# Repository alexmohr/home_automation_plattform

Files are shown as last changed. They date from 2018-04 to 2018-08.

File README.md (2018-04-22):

# Home automation plattform 
PCB and schematic for my personal home automation plattform.
Contains temperature sensor, LDR, 433Mhz, 836Mhz, Infrared led, Infrared input. 
It provides an easy way to turn a raspberry pi into a home automation centre, when used together with home assistant. 

Made for raspberry pi 3 with ♥

## Used devices
[CC1101](https://www.aliexpress.com/item/CC1101-Wireless-Module-Long-Distance-Transmission-Antenna-868MHZ-M115/32635393463.html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,searchweb201602_5_10320_10152_10321_10065_10151_10344_10068_10342_10547_10343_10322_10340_10548_10341_10698_10697_10193_10696_10194_10084_10083_10618_10304_10307_10302_10180_10059_10184_308_100031_10319_10103_441_10624_10623_10622_10186_10621_10620,searchweb201603_15,ppcSwitch_5&algo_expid=a848840e-54c4-47bb-ab77-2ef09451083a-1&algo_pvid=a848840e-54c4-47bb-ab77-2ef09451083a&priceBeautifyAB=0)

[BME280](https://www.aliexpress.com/item/BME280-Digital-Sensor-Temperature-Humidity-Barometric-Pressure-Sensor-Module-I2C-SPI-1-8-5V-GY-BME280/32850070226.html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,searchweb201602_5_10320_10152_10321_10065_10151_10344_10068_10342_10547_10343_10322_10340_10548_10341_10698_10697_10193_10696_10194_10084_10083_10618_10304_10307_10302_10180_10059_10184_308_100031_10319_10103_441_10624_10623_10622_10186_10621_10620,searchweb201603_15,ppcSwitch_5&algo_expid=3042d4b9-162d-4179-8373-1a698f202e66-0&algo_pvid=3042d4b9-162d-4179-8373-1a698f202e66&priceBeautifyAB=0)

[2TN2222A](https://www.aliexpress.com/item/2N2222A-Free-shipping-100pcs-in-line-triode-transistor-NPN-switching-transistors-TO-92-0-6A-30V/32816748799.html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,searchweb201602_5_10320_10152_10321_10065_10151_10344_10068_10342_10547_10343_10322_10340_10548_10341_10698_10697_10193_10696_10194_10084_10083_10618_10304_10307_10302_10180_10059_10184_308_100031_10319_10103_441_10624_10623_10622_10186_10621_10620,searchweb201603_15,ppcSwitch_5&algo_expid=e6ef298e-db4e-4916-be07-d07086949b34-2&algo_pvid=e6ef298e-db4e-4916-be07-d07086949b34&priceBeautifyAB=0)

[Infrared LED](https://www.aliexpress.com/item/10-Pcs-5mm-100mW-Infrared-IR-LED-Night-Vision-940nm-invisible-Diode-60-degree-Led-Light/32491780864.html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,searchweb201602_5_10320_10152_10321_10065_10151_10344_10068_10342_10547_10343_10322_10340_10548_10341_10698_10697_10193_10696_10194_10084_10083_10618_10304_10307_10302_10180_10059_10184_308_100031_10319_10103_441_10624_10623_10622_10186_10621_10620,searchweb201603_15,ppcSwitch_5&algo_expid=32d9c39a-0b61-410d-89fb-16560a7c7f51-0&algo_pvid=32d9c39a-0b61-410d-89fb-16560a7c7f51&priceBeautifyAB=0)

[Generic 433Mhz Transmitter](https://www.aliexpress.com/item/433M-TX-RX-Super-regenerative-Module-Wireless-Transmitting-Module-Alarm-Transmitter-Receiver/2024422377.html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,searchweb201602_5_10320_10152_10321_10065_10151_10344_10068_10342_10547_10343_10322_10340_10548_10341_10698_10697_10193_10696_10194_10084_10083_10618_10304_10307_10302_10180_10059_10184_308_100031_10319_10103_441_10624_10623_10622_10186_10621_10620,searchweb201603_15,ppcSwitch_5&algo_expid=0122146b-dcd8-4e24-963f-864d1bfaabf2-0&algo_pvid=0122146b-dcd8-4e24-963f-864d1bfaabf2&priceBeautifyAB=0)

Not linked: 
- 10k Ohm resistor
- 0.22 Farad Capacitor ( because basically it is redicously too large but was lying arround. Any other 5V capacitor will do just fine. The light threshold must be adjusted acordingly ) 

See https://github.com/alexmohr/raspberrypi-mqtt-light-sensor

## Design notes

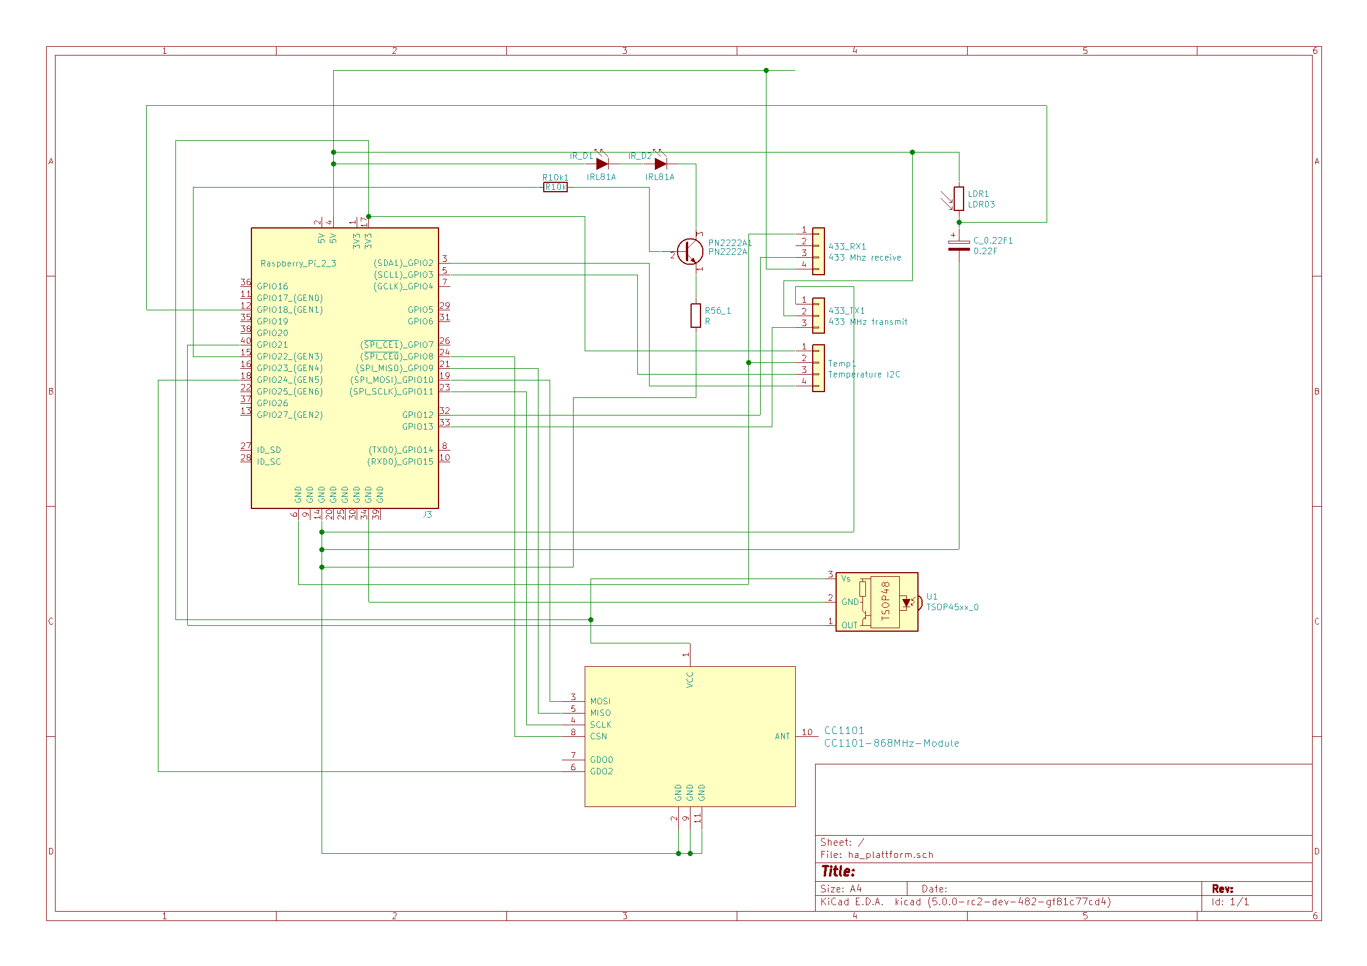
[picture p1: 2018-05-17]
pi/export_as_image/schematic.png

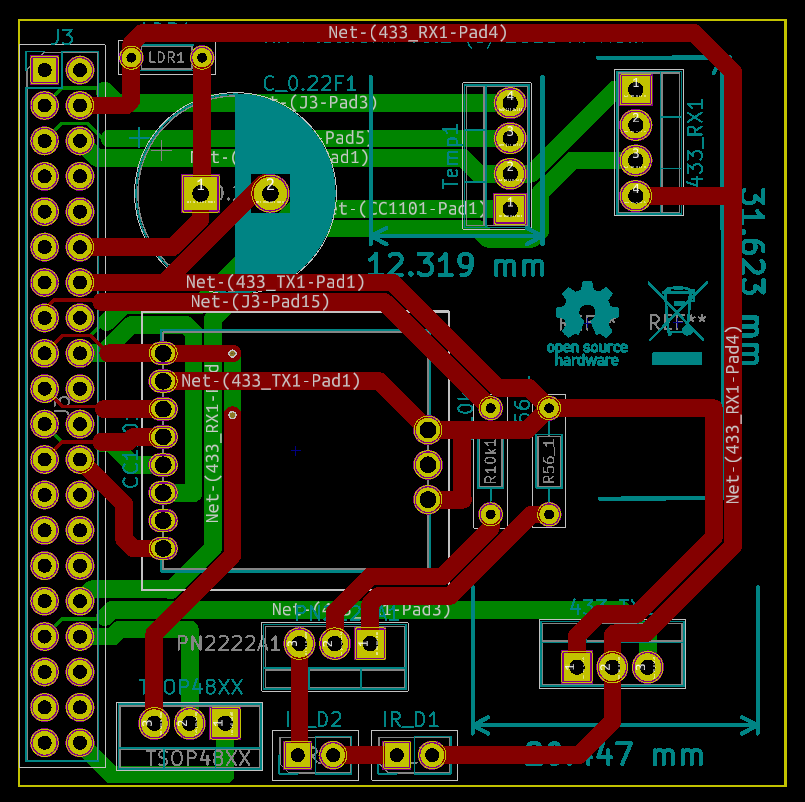
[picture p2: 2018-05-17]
pi/export_as_image/layout.png

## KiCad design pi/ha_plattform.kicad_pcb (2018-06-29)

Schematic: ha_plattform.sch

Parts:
433_RX1: 433 Mhz receive; RF_Receiver_433_MHz
433_TX1: 433 MHz transmit; RF_Transmitter_433_MHz
CC1101: CC1101-868MHz-Module
C_0.22F1: 0.22F; CP_Radial_D5.0mm_P2.50mm
IR_D1, IR_D2: IRL81A; LED_D3.0mm_Horizontal_O6.35mm_Z10.0mm
J3: Raspberry_Pi_2_3; PinHeader_2x20_P2.54mm_Vertical
LDR1: LDR03; R_Axial_DIN0204_L3.6mm_D1.6mm_P5.08mm_Horizontal
PN2222A1: PN2222A; TO-220-3_Vertical
R10k1: R10k; R_Axial_DIN0204_L3.6mm_D1.6mm_P7.62mm_Horizontal
R56_1: R; R_Axial_DIN0204_L3.6mm_D1.6mm_P7.62mm_Horizontal
TSOP48xx_1: TSOP45xx_0; TO-220-3_Vertical
Temp1: Temperature I2C; TO-220-4_Vertical

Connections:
unnamed: 433_RX1.1, J3.6 (GND), Temp1.2
unnamed: 433_RX1.3, J3.32 (GPIO12)
unnamed: 433_RX1.4, 433_TX1.2, IR_D1.2 (A), J3.4 (5V), LDR1.1
unnamed: 433_TX1.1, CC1101.2, CC1101.9, CC1101.11, C_0.22F1.2, J3.14 (GND), R56_1.2
unnamed: 433_TX1.3, J3.33 (GPIO13)
unnamed: CC1101.1, J3.17 (3V3), TSOP48xx_1.3 (Vs)
unnamed: CC1101.3, J3.19 ((SPI_MOSI)_GPIO10)
unnamed: CC1101.4, J3.23 ((SPI_SCLK)_GPIO11)
unnamed: CC1101.5, J3.21 ((SPI_MISO)_GPIO9)
unnamed: CC1101.6, J3.18 (GPIO24_(GEN5))
unnamed: CC1101.8, J3.24 ((~SPI_CE0~)_GPIO8)
unnamed: C_0.22F1.1, J3.29 (GPIO5), LDR1.2
unnamed: IR_D1.1 (K), IR_D2.2 (A)
unnamed: IR_D2.1 (K), PN2222A1.3 (C)
unnamed: J3.1 (3V3), Temp1.1
unnamed: J3.3 ((SDA1)_GPIO2), Temp1.4
unnamed: J3.5 ((SCL1)_GPIO3), Temp1.3
unnamed: J3.15 (GPIO22_(GEN3)), R10k1.1
unnamed: J3.34 (GND), TSOP48xx_1.2 (GND)
unnamed: J3.40 (GPIO21), TSOP48xx_1.1 (OUT)
unnamed: PN2222A1.1 (E), R56_1.1
unnamed: PN2222A1.2 (B), R10k1.2

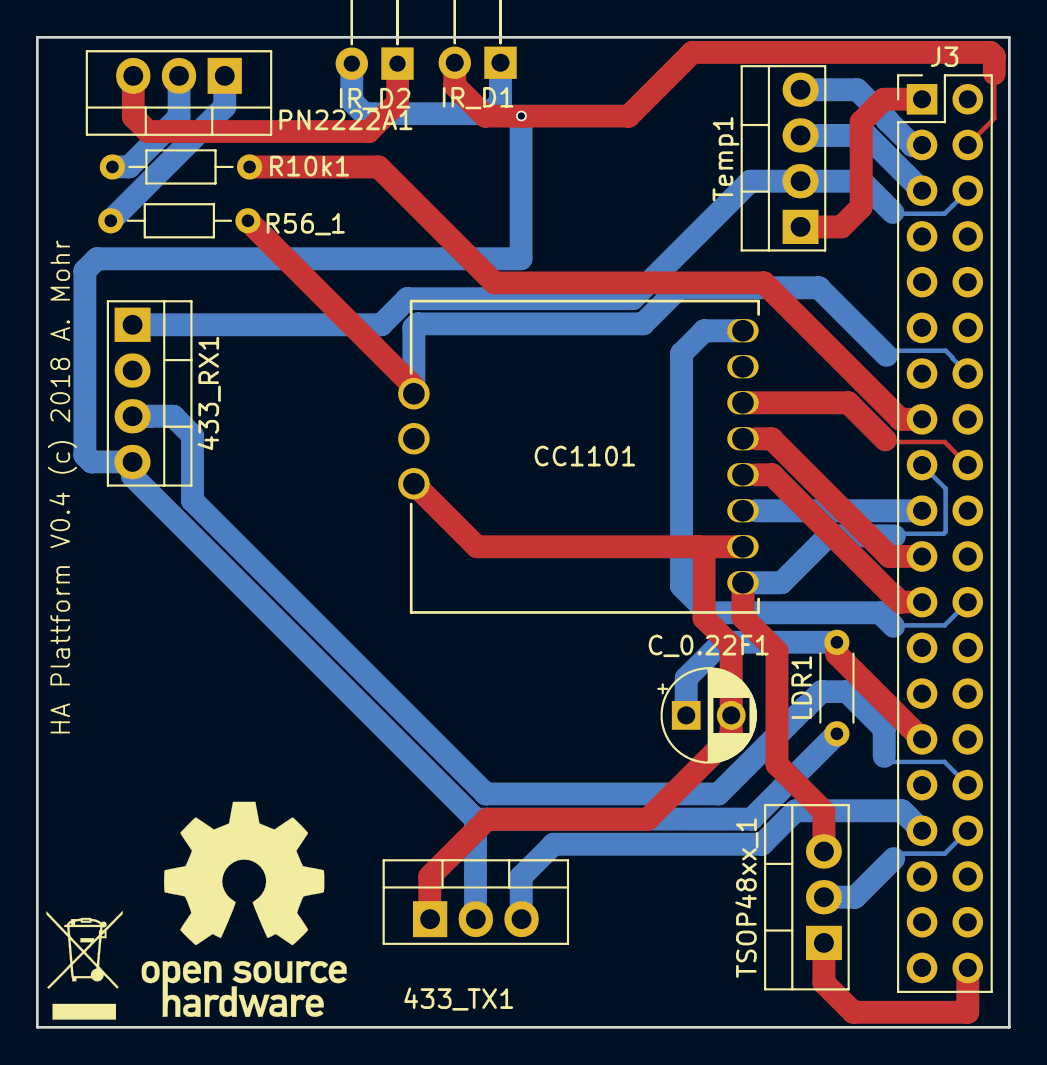
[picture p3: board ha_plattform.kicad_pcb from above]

Board: 2 copper layers, 54.0 x 55.0 mm, 13 parts (0 on the bottom side), 22 nets.

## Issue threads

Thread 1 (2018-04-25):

Replace light dependent resistor

alexmohr, 2018-04-25:
The ldr should be replaced with a digital module to get better precision.

Closed 2018-05-15.

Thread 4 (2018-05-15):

temperature module

alexmohr, 2018-05-15:
verfify spacing and correct wrong pinout

Closed 2018-05-19.

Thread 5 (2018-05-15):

Missing resistor

alexmohr, 2018-05-15:
Prototype has resistor at emitter (?) Of transitor. Probably to protect LEDs. Check if it should be added to PCB.

Closed 2018-05-17.

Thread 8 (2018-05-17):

Verify Spacing

alexmohr, 2018-05-17:
Verify that all spacing is correct so version 2 can be manufatured.

alexmohr, 2018-05-17:
Make sure that the edge cuts are small enough to fit in the case this time.

alexmohr, 2018-05-17:
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

Closed 2020-10-03.

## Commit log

2018-04-20 Inital commit
    [ha_plattform-2018-04-19-19-32-51.sch, ha_plattform-2018-04-19-19-36-09.sch, ha_plattform-2018-04-19-19-40-52.sch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]
2018-04-22 I new file: _autosave-ha_plattform.kicad_pcb
2018-04-22 Added static images to view wihtout kicad
2018-04-23 Changed track width, improved routing
    [ha_plattform-B.Cu.gbl, ha_plattform-B.Mask.gbs, ha_plattform-B.SilkS.gbo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]
2018-04-23 changed details for fabrication
    [ha_plattform-B.Cu.gbl, ha_plattform-B.Mask.gbs, ha_plattform-B.SilkS.gbo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]
2018-05-15 Reduced layout size to fit into case
    [ha_plattform-B.Cu.gbl, ha_plattform-B.Mask.gbs, ha_plattform-B.SilkS.gbo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]
2018-05-15 Increased space between 433mhz modules
    [ha_plattform.kicad_pcb]
2018-05-17 fixed layout issues. moved led to front. rerouted whole board
    [ha_plattform.kicad_pcb, ha_plattform.sch]
2018-05-17 Updated images and gerber files. Added don't trash and open hardware symbol
    [ha_plattform-B.Cu.gbl, ha_plattform-B.Mask.gbs, ha_plattform-B.SilkS.gbo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]
2018-05-18 Changed minor things
    [ha_plattform.kicad_pcb]
2018-05-21 reduced footprint for capacitor
    [ha_plattform-B.Cu.gbl, ha_plattform-B.Mask.gbs, ha_plattform-B.SilkS.gbo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]
2018-05-24 Updated gerber files. Prepared for manufacturing
    [ha_plattform-B.Cu.gbl, ha_plattform-B.Mask.gbs, ha_plattform-B.SilkS.gbo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]
2018-06-07 Fixed layout, so the pinheader are on the correct side...
    [ha_plattform-B.Cu.gbl, ha_plattform-B.Mask.gbs, ha_plattform-B.SilkS.gbo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]
2018-06-08 Prepared version 0.3.
    [ha_plattform-B.Cu.gbl, ha_plattform-B.Mask.gbs, ha_plattform-B.SilkS.gbo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]
2018-06-24 Added layout for nodemcu
    [_saved_nodemcu.sch, ha_plattform-2018-04-19-19-32-51.sch, ha_plattform-2018-04-19-19-36-09.sch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]
2018-06-29 Rerouted because footprints of 433mhz rx/tx were wrong-32-51.sch
    [_saved_nodemcu.sch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]
2018-08-02 fixed size for node mcu
    [_saved_nodemcu.sch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]

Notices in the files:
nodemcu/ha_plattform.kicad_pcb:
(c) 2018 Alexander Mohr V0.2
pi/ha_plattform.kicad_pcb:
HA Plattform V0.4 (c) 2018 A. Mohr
